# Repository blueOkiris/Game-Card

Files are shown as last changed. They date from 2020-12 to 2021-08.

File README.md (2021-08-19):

# Game Card

## Description

A business card sized portable game console utilizing buttons, multiple games, and an i2c display

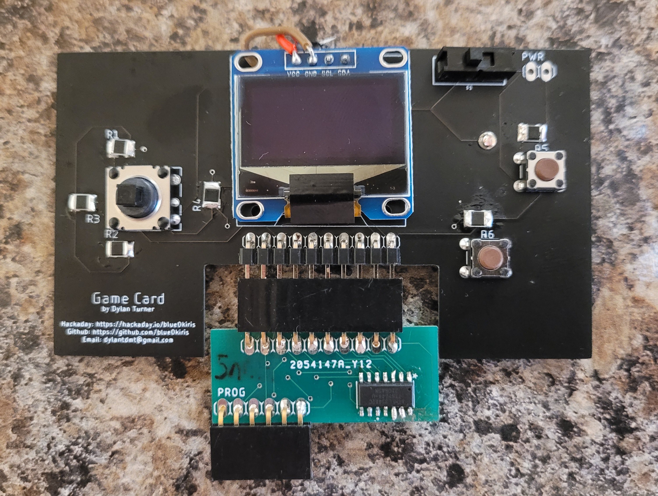
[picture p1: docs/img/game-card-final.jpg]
Game Card Final Image


[YouTube Video](https://www.youtube.com/watch?v=qE-Pg2zxOUw)

## Improving the Design (HELP!)

Right now I'm trying to redesign a new version where I can source all the electronics from manufacturers for a few reasons including:
 * Putting them up for sale
 * Decreasing cost
 * Simplifying build time

I've got everything redesigned and sourced except for the display. These little OLEDs are available everywhere except distributers it seems, and while they're like \$1-3 usually, I can't find sourcable ones for PCBs under \$10.

When the rest of the electronics costs \$4 total, it seems insane for it to be almost $15 to make.

If you can find a source I can use to build this, PLEASE let me know!

## Game List

Currently there are three games developed for the Game Card:

- Ping (1 and 2 player pong clone)
- Snek (Snake clone)
- In Progress: Tiny RPG (a very small RPG)

## More Links
 - [Info on Design](/docs/DESIGN.md)
 - [Info on Programming Cartridges](/docs/PROGRAMMING.md)
 - [Hackaday Project Page](https://hackaday.io/project/178686-game-card)

NOTE: If you're looking for the PCB designs and parts for the cartridges and cards, they're on the hackaday page

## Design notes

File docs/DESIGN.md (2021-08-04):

# Design

## Overall

The Game Card itself is nothing but a shell containing the I2C display and buttons.
Each game can then utilize the hardware how it likes and in the most efficient way possible.

The original cartridges use ATtiny84As as the brains and ROM.

Included in this repo are games designed for the system as well as header-only libraries utilizable by the various applications.

## OLED Display Connection

The OLED display is connected through the two designated I2C pins on the ATtiny84A.
These are pins 4 (SCL) and 6 (SDA) in Arduino code or 7 and 9 on the actual device.

They are also the 5th and 6th pins on the PCB port if counting from right to left.

## Button Connection

The buttons are wired in the following order:
 - Lower Button - 3rd pin from the right on PCB (first 2 are GND then VCC) which corresponds to Arduino pin 10/ATtiny pin B0
 - Higher Button - 4th pin from the right on PCB corresponding to Arduino 9/ATtiny B1
 - Up - 7th pin from the right on PCB/Arduino 8/B2
 - Down - 8th pin from the right on PCB/Arduino 7/A7
 - Left - 9th pin from the right on PCB/Arduino 5/A5
 - Right - Last pin from the right on PCB/Arduino 0/A0

Note that H and L are pulled down, but Up/Down/Left/Right are all pulled up, so they're inverted!
Just use the library though and you'll be fine :)

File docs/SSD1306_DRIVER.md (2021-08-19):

# SSD1306 Custom Driver Board

## Version 4 Need

In making Version 4 of the system, I *really* wanted to source all the parts from manufacturers so that I could order boards with the parts pre-soldered, so I could feasibly sell them.

The only sourcable I2C SSD1306 I could find was [this](https://www.newark.com/midas/mdob128064v2v-yi/oled-graphic-display-cob-128x64pixels/dp/21AH3309).

It's... okay, but at almost \$14, it outclasses all other components which total \$3.00 even.
Yeah, kinda dumb.

I looked at all the major retailers, but found no luck, despite the fact you can find them at various online stores for as low as $1.25.

Solution?
Build my own driver board. It's not as bad as it seems actually. It's pretty simple.

I'm documenting this here so I can put it in one handy place for reference. It doesn't really have to do with code itself though.

## I2C Selection

These boards can communicate in a variety of ways, including Parallel, SPI, and IIC.
I've always used I2C for these throughout the project, and I want full compatibility with the current codebase (though I think I may be able to do parallel, so that is unfortunate, but it's too late).

Anyway, that selection has to be done in hardware by tying various pins together on the ribbon cable.

The datasheet is pretty helpful in this regard.

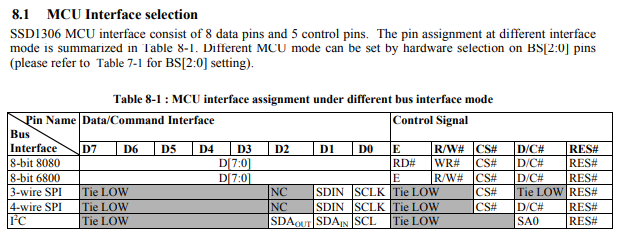
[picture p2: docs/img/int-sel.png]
int-sel


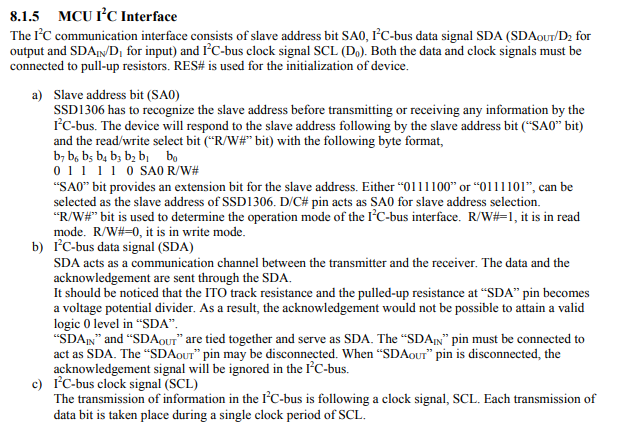
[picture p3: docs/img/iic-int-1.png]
iic-int-1


Things to note:
* Looking at the current driver board and code, I know that the SA0 bit is tied to ground as the I2C address is 0x3C.
* The R/W\# pin is obviously tied to ground because we want to write to it
* SDA\_in and SDA\_out are tied to together for one SDA
* D7:3 are tied to GND while D2:1 are tied to SDA.
* E and CS# are both low
* Reset is high bc we don't want it to reset.

## Driver Circuit

Adafruit provides a driver circuit that I think I can use as a reference for my own design:

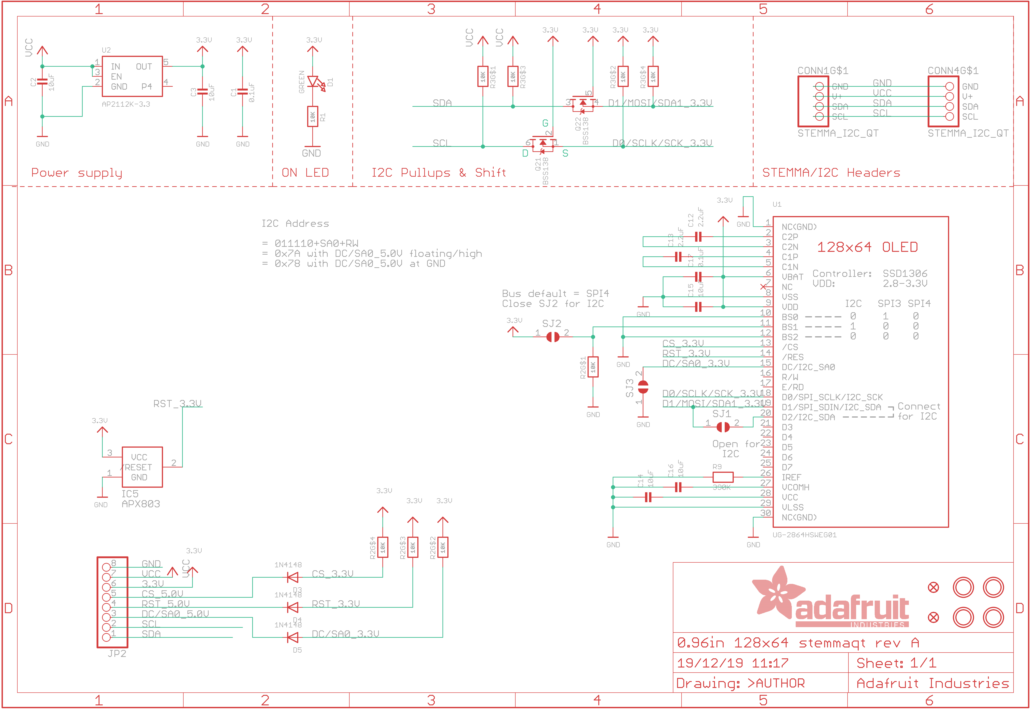
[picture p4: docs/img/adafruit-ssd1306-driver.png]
adafruit i2c display circuit


It's... okay.
I found a simpler one though:

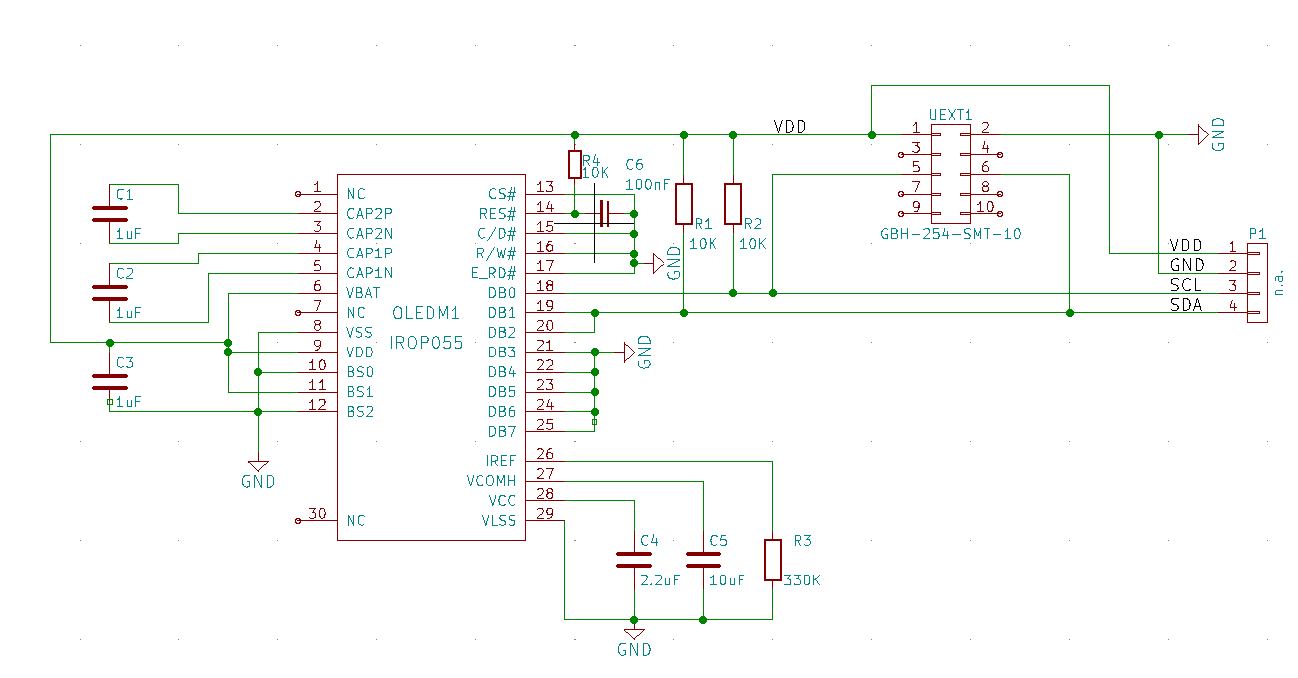
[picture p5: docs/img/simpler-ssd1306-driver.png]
simpler i2c ssd1306


But I'm not certain it's actually setting everything up correctly.

Got it from [here](https://www.olimex.com/Products/Modules/LCD/MOD-OLED-128x64/open-source-hardware)

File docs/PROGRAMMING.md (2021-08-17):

# Programming a Cartridge

## Info

This assumes you are using the standard ATtiny84 cartridges.

This is how to set up your dev environment to be able to get these programs to those game cartridges.

## Install build tool

First, install `make`.

If you're on windows, install MinGW from [here](http://sourceforge.net/projects/mingw-w64/files/Toolchains%20targetting%20Win32/Personal%20Builds/mingw-builds/installer/mingw-w64-install.exe/download)

That will give you access to the command `mingw32-make` which is an equivalent to `make` on Linux.

Linux users, simply use your package manager to install make. On Ubuntu/Debian, the package is within "build-essential."

After that, go to the official arduino page and install the Arduino IDE.

NOTE: If you're on Linux, you also need to change lines 6 and 7 of arduino-cli.yaml to use / instead of \\!

## Setup UNO

Open up the Arduino IDE and find the example "ArduinoISP" program in the Arduino IDE, select the UNO from the menu (noting the PORT for later), and program the UNO with the Arduino ISP program.

Once you've configured your UNO as a programmer, you won't need to open the IDE again.

## Connect Board

Once you have make, and your UNO is set up, you'll need to connect the cartridge to an Arduino UNO.

From Right to left on Programming port the connections are 5V, GND, 12, 11, 13, and 10

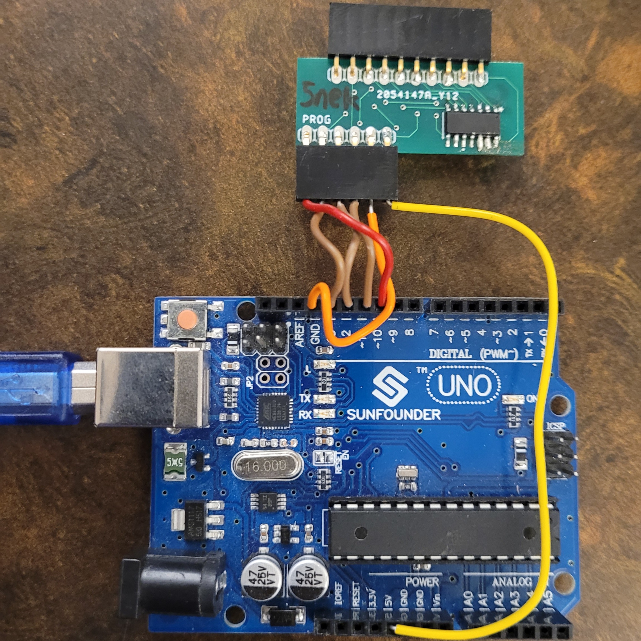
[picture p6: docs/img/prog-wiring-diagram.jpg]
prog-wiring-diagram


## Burn-Bootloader

With everything set up, first burn the bootloader:
 - Linux: `make burn-bootloader PORT=#####`
 - Windows: `mingw32-make burn-bootloader PORT=#####`

Replace the pound signs after `PORT=` with the UNO's port from earlier.

## Program Game

Then program the game!

 - Linux: `make PORT=##### GAME=#####`
 - Windows: `mingw32-make PORT=##### GAME=#####`

Once again, replace the pound signs after `PORT=` with the UNO's port from earlier, but also replace the pound signs after `GAME=` with the name of the game you'd like to program be that Snek, Ping, or otherwise.

And you're done!

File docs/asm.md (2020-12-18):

# Assembly Programming Guide

## Description

Here I describe how to program for the Game Card in Game Card Assembly using the Game Card Assembler (gca).

See [example.gca](./example.gca) for an example of gca code

## Instructions

__Memory Control__

There are several commands for manipulating memory.

Some can set tile mem, background mem, and sprite mem, but those are the most complicated. I'll start first with registers and move from there.

The first instruction we'll look at is `mov`

`mov` takes a register indicated by "reg" followed by an index, a comma, and a value which is either an integer value, a hex value, or another register.

This command takes whatever datum follows the column and stores it in the register.

Examples:
- `mov reg0, 1237`
- `mov reg1, reg0`
- `mov reg2, 0xF78`

Adding onto that are arithmetic commands which store the value of the first register plussed or minused or whatever with the value back into the first register.

So `add reg1, reg2` is like `reg1 += reg2` or `reg1 = reg1 + reg2`

So you have `add` for `+`, `sub` for `-`, `mul` for `*`, `div` for `/`, `ls` for left shift, `rs` for right shift.

Now these can also apply to parts of sprite memory, specifically a sprites x and y position:
- `mov sprx, 0, 10`
- `add spry, reg1, 0x57`

Note:
 - There are *3* comma separated values. The first is sprx or spry, the second is which sprite you want to change, and the third is the new value as per the register versions
 - sprx and spry cannot be in the value part of the command

Even more specialized are the sprite's tile index, `spri`, a background location's tile index, `bgi`, an entire sprite, `spr`, and tiles, `tile`

__Graphical Setting__

<u>Sprites:</u>
Set an entire sprite by providing index, x, y, and then tile:

`spr <sprite index>, <x position>, <y position>, <tile index>`
All of these can be registers or discrete numbers (including hex)

Example:
`spr 0, 5, 5, 1` sets sprite 0 to be at position (5, 5) with image #1

<u>Backgrounds:</u>
`bgi` Works similarly, but with less values, just index and tile:
`bgi <bg index>, <tile index>`

Example:
`bgi reg0, 0x0F`

<u> Tiles: </u>
`tile` takes an index followed by 8 bytes representing columns

Example:
`tile 1, 0xFF, 0x81, 0x81, 0x81, 0x81, 0x81, 0x81, 0xFF` sets the tile at index 1 to be a box

__Labels and Jumps__

The other part of the assembly language is control flow

You can set named points in a program to jump to either unconditionally or with condition.

A name plus ':' makes a label - `label_name_HERE69:`
You can then jump to it with `jmp label_nameHERE69`

These jumps can be based on conditions:
 - `je` - Jump if equal
 - `jne` - Jump if not equal
 - `jl` - Jump if less than
 - `jg` - Jump if greater than
 - `jle` - Jump if less than or equal
 - `jge` - Jump if greater than or equal

The way you set those conditions is with `cmp` (compare)

`cmp` takes two registers and compares them, setting an internal register which can be used in conditional jumps

Example:
```
label_for_loop:
    cmp reg0, reg1
    jg label_if_reg0_is_greater_than
    mov reg0, reg1
    add reg0, 1
    jmp label_for_loop
label_if_reg0_is_greater_than:
```

This code will compare reg0 to reg1, and if reg0 is NOT greater than reg1, it will set reg0 to reg1 + 1 then jump back to compare again.

If reg0 WAS greater than reg1, or the second time through where it MUST be reg0, then it will jump out of the loop to `label_if_reg0_is_greater_than`

__Comments__

Comments are anything following a ';' until a new line

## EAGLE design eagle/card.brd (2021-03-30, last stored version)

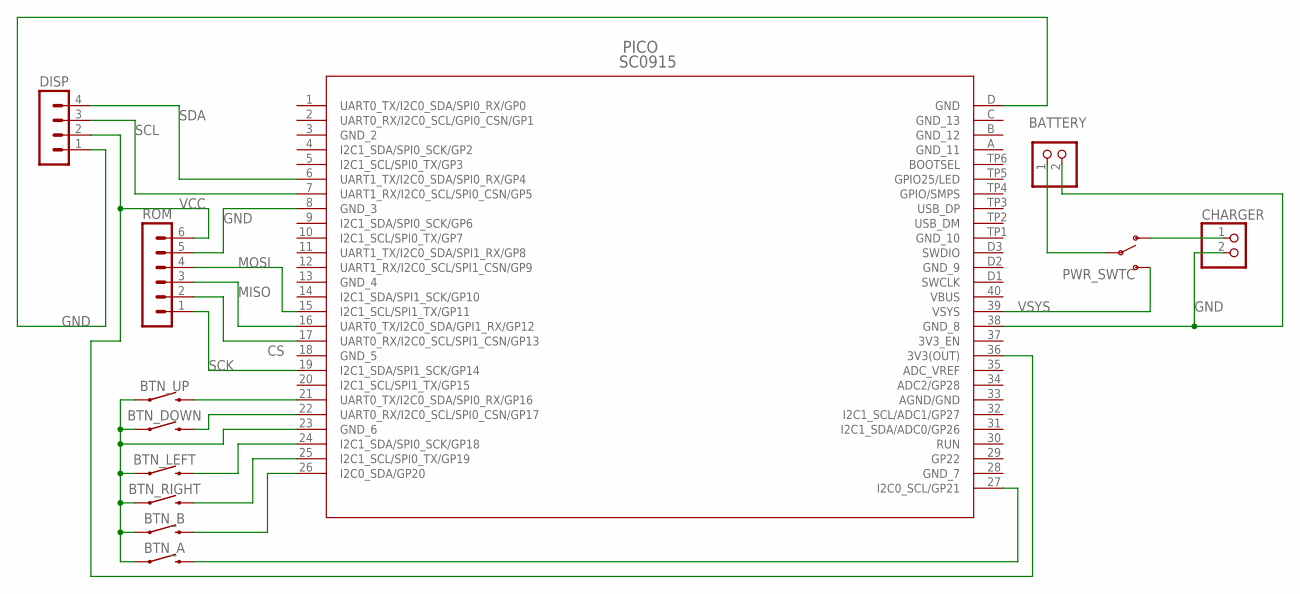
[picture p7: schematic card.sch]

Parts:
BATTERY: PINHD-1X2; 1X02
BTN_A: MOMENTARY-SWITCH-SPST-PTH-6.0MM; TACTILE_SWITCH_PTH_6.0MM
BTN_B: MOMENTARY-SWITCH-SPST-PTH-6.0MM; TACTILE_SWITCH_PTH_6.0MM
BTN_DOWN: MOMENTARY-SWITCH-SPST-PTH-6.0MM; TACTILE_SWITCH_PTH_6.0MM
BTN_LEFT: MOMENTARY-SWITCH-SPST-PTH-6.0MM; TACTILE_SWITCH_PTH_6.0MM
BTN_RIGHT: MOMENTARY-SWITCH-SPST-PTH-6.0MM; TACTILE_SWITCH_PTH_6.0MM
BTN_UP: MOMENTARY-SWITCH-SPST-PTH-6.0MM; TACTILE_SWITCH_PTH_6.0MM
CHARGER: PINHD-1X2; 1X02
DISP: MA04-1
PICO: SC0915; SC0915_RPI
PWR_SWTC: SWITCH-SPDT-PTH-11.6X4.0MM; SWITCH_SPDT_PTH_11.6X4.0MM
ROM: MA06-1

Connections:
3V3_EN: PICO.37 (3V3_EN)
ADC_VREF: PICO.35 (ADC_VREF)
CS: PICO.17 (UART0_RX/I2C0_SCL/SPI1_CSN/GP13), ROM.2
GND: BATTERY.2, BTN_A.1, BTN_B.1, BTN_DOWN.1, BTN_LEFT.1, BTN_RIGHT.1, BTN_UP.1, CHARGER.2, DISP.1, PICO.8 (GND_3), PICO.23 (GND_6), PICO.38 (GND_8), PICO.D (GND), ROM.5
MISO: PICO.16 (UART0_TX/I2C0_SDA/GPI1_RX/GP12), ROM.3
MOSI: PICO.15 (I2C1_SCL/SPI1_TX/GP11), ROM.4
unnamed: BTN_UP.3 (2), PICO.21 (UART0_TX/I2C0_SDA/SPI0_RX/GP16)
unnamed: BTN_DOWN.3 (2), PICO.22 (UART0_RX/I2C0_SCL/SPI0_CSN/GP17)
unnamed: BTN_LEFT.3 (2), PICO.24 (I2C1_SDA/SPI0_SCK/GP18)
unnamed: BTN_RIGHT.3 (2), PICO.25 (I2C1_SCL/SPI0_TX/GP19)
unnamed: BTN_B.3 (2), PICO.26 (I2C0_SDA/GP20)
unnamed: BTN_A.3 (2), PICO.27 (I2C0_SCL/GP21)
unnamed: BATTERY.1, PWR_SWTC.2
unnamed: CHARGER.1, PWR_SWTC.1 (O)
SCK: PICO.19 (I2C1_SDA/SPI1_SCK/GP14), ROM.1
SCL: DISP.3, PICO.7 (UART1_RX/I2C0_SCL/SPI0_CSN/GP5)
SDA: DISP.4, PICO.6 (UART1_TX/I2C0_SDA/SPI0_RX/GP4)
VBUS: PICO.40 (VBUS)
VCC: DISP.2, PICO.36 (3V3(OUT)), ROM.6
VSYS: PICO.39 (VSYS), PWR_SWTC.3 (S)

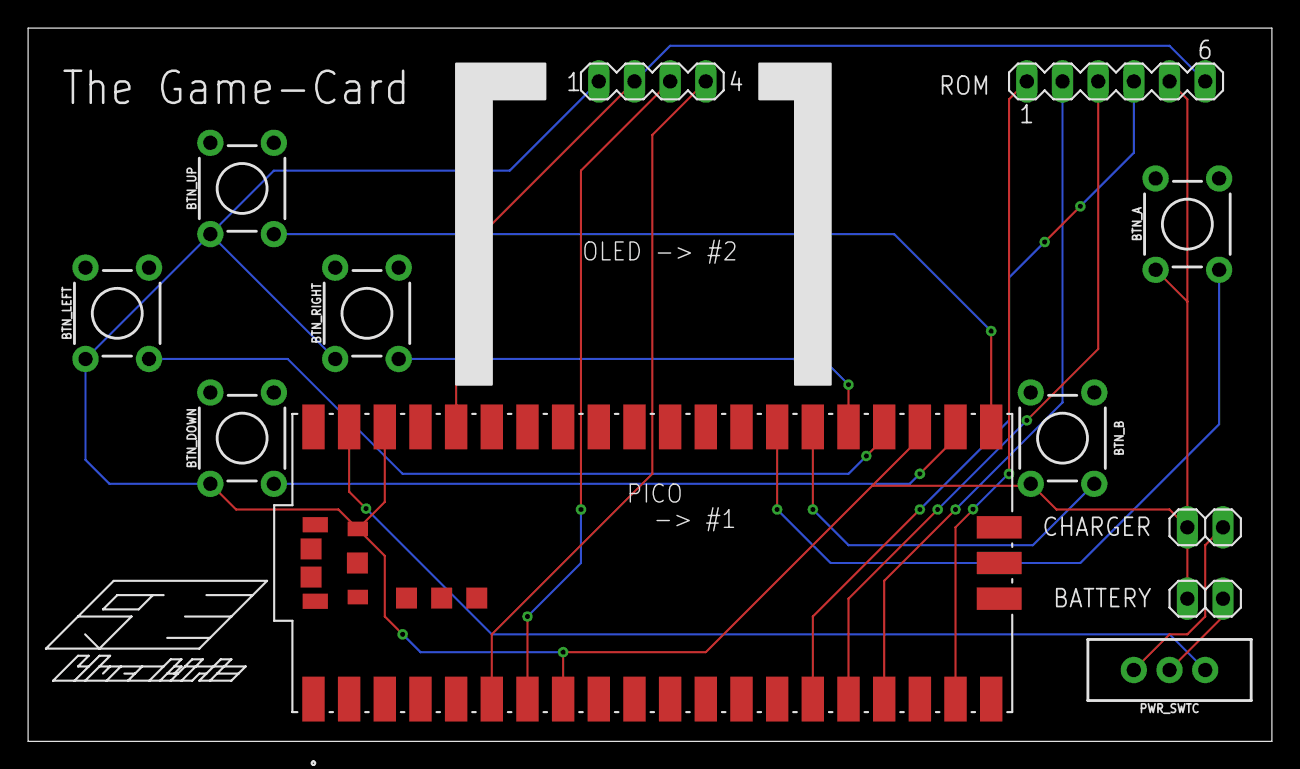
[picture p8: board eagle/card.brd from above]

Board: 2 copper layers, 88.6 x 50.8 mm, 12 parts (0 on the bottom side), 17 nets.

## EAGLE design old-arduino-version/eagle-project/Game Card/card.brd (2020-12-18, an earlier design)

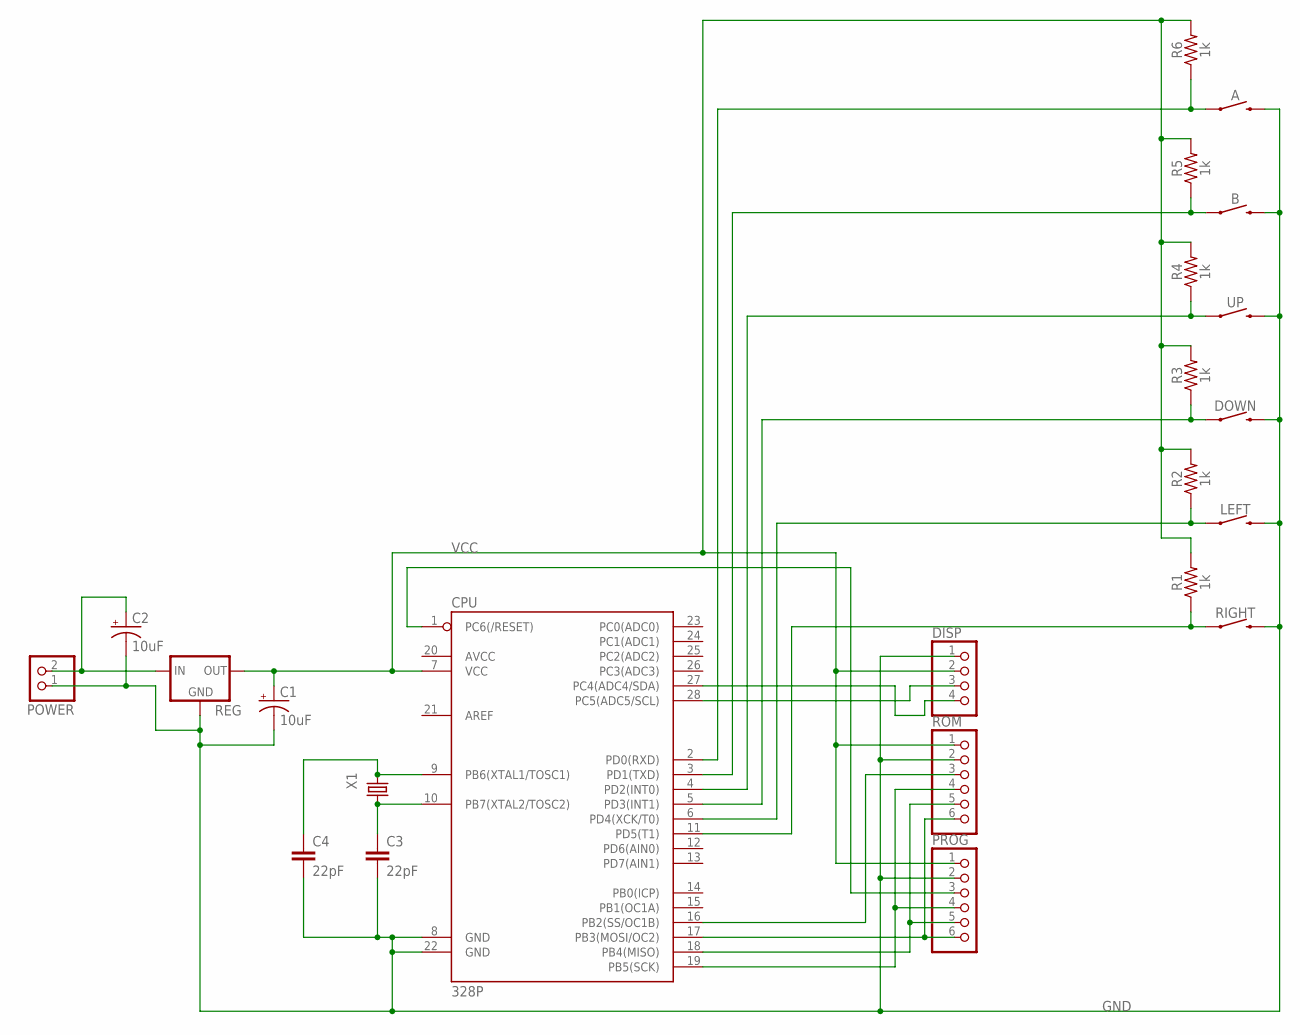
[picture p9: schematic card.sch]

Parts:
A: MOMENTARY-SWITCH-SPST-PTH-6.0MM; TACTILE_SWITCH_PTH_6.0MM
B: MOMENTARY-SWITCH-SPST-PTH-6.0MM; TACTILE_SWITCH_PTH_6.0MM
C1, C2: 10uF; CPOL-RADIAL-2.5MM-5MM
C3, C4: 22pF; CAP-PTH-2.54
CPU: 328P; DIP28
DISP: PINHD-1X4; 1X04
DOWN: MOMENTARY-SWITCH-SPST-PTH-6.0MM; TACTILE_SWITCH_PTH_6.0MM
LEFT: MOMENTARY-SWITCH-SPST-PTH-6.0MM; TACTILE_SWITCH_PTH_6.0MM
POWER: PINHD-1X2; 1X02
PROG: PINHD-1X6; 1X06
R1, R2, R3, R4, R5, R6: 1k; AXIAL-0.3
REG: R-78E5.0-1.0; DC-DC_CONVERTER_78XX
RIGHT: MOMENTARY-SWITCH-SPST-PTH-6.0MM; TACTILE_SWITCH_PTH_6.0MM
ROM: PINHD-1X6; 1X06
UP: MOMENTARY-SWITCH-SPST-PTH-6.0MM; TACTILE_SWITCH_PTH_6.0MM
X1: CRYSTALS-NOGND-HC49; HC49

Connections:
GND: A.3 (2), B.3 (2), C1.2 (-), C2.2 (-), C3.2, C4.2, CPU.8 (GND), CPU.22 (GND), DISP.1, DOWN.3 (2), LEFT.3 (2), POWER.1, PROG.2, REG.GND, RIGHT.3 (2), ROM.2, UP.3 (2)
unnamed: CPU.17 (PB3(MOSI/OC2)), PROG.6, ROM.6
unnamed: CPU.18 (PB4(MISO)), PROG.5, ROM.5
unnamed: CPU.19 (PB5(SCK)), PROG.4, ROM.4
unnamed: CPU.1 (PC6(/RESET)), PROG.3
unnamed: A.1, CPU.2 (PD0(RXD)), R6.P$1 (1)
unnamed: C2.1 (+), POWER.2, REG.VIN (IN)
unnamed: CPU.16 (PB2(SS/OC1B)), ROM.3
unnamed: CPU.28 (PC5(ADC5/SCL)), DISP.3
unnamed: CPU.27 (PC4(ADC4/SDA)), DISP.4
unnamed: C4.1, CPU.9 (PB6(XTAL1/TOSC1)), X1.2
unnamed: B.1, CPU.3 (PD1(TXD)), R5.P$1 (1)
unnamed: CPU.4 (PD2(INT0)), R4.P$1 (1), UP.1
unnamed: CPU.5 (PD3(INT1)), DOWN.1, R3.P$1 (1)
unnamed: CPU.6 (PD4(XCK/T0)), LEFT.1, R2.P$1 (1)
unnamed: CPU.11 (PD5(T1)), R1.P$1 (1), RIGHT.1
unnamed: C3.1, CPU.10 (PB7(XTAL2/TOSC2)), X1.1
VCC: C1.1 (+), CPU.7 (VCC), DISP.2, PROG.1, R1.P$2 (2), R2.P$2 (2), R3.P$2 (2), R4.P$2 (2), R5.P$2 (2), R6.P$2 (2), REG.VOUT (OUT), ROM.1

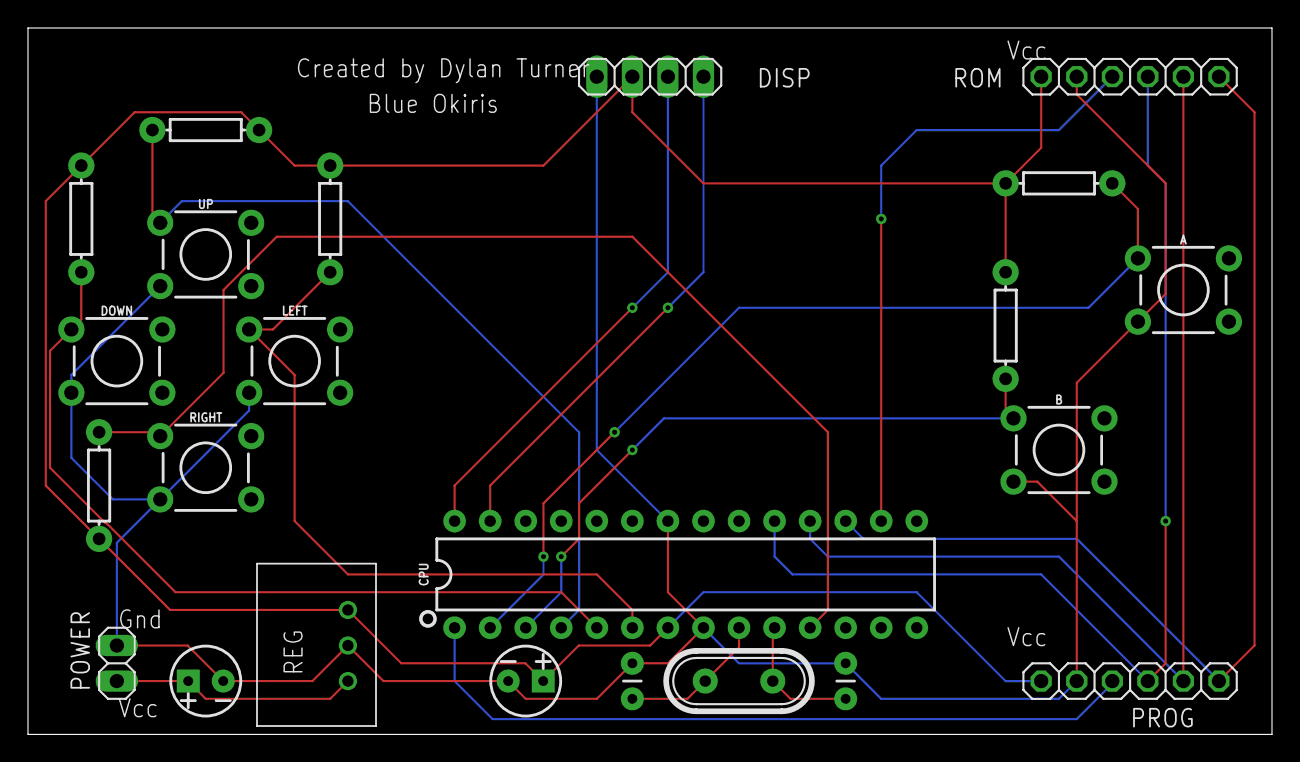
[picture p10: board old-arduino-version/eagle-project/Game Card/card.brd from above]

Board: 2 copper layers, 88.9 x 50.5 mm, 23 parts (0 on the bottom side), 18 nets.

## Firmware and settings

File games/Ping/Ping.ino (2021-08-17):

/*
 * Author: Dylan Turner
 * Description: A pong clone for 1 and 2 players
 */

#include <GameCardDisplay.hpp>
#include <GameCardControls.hpp>
#include "State.hpp"
#include "Sprites.hpp"

const gamecard::Ssd1306 g_disp;
const gamecard::ButtonController g_cont;
GameState g_state;

void setup(void) {
    g_disp.init();
    g_cont.init();
}

void loop(void) {
    switch(g_state.curr) {
        case GameState::StateName::Menu:
            g_state.reset();
            g_disp.fill(true);
            
            drawMenu();

            // Wait for player count
            while(!g_state.twoPlayer) {
                if(g_cont.isInputPressed(gamecard::Input::High)) {
                    break;
                } else if(g_cont.isInputPressed(gamecard::Input::Low)) {
                    g_state.twoPlayer = true;
                }
            }

            // Continue
            randomSeed(millis());
            g_state.curr = GameState::StateName::Game;
            resetPostScore();
            break;

        case GameState::StateName::Game:
            drawScore();
            
            drawPaddles();
            movePaddles();

            clearBall();
            moveBallAndScore();
            drawBall();

            /*
             * Switching to TinyWireM
             * didn't just save memory
             * it drastically improved draw speeds
             * so we have to delay now
             * (This is a good thing)
             */
            delay(5);
            break;

        case GameState::StateName::End:
            g_disp.fill(true);
            drawWinner();
            while(!g_cont.isInputPressed(gamecard::Input::High));
            delay(1);
            while(g_cont.isInputPressed(gamecard::Input::High));
            g_state.curr = GameState::StateName::Menu;
            break;
    }
}

bool updateMoveDirection(
        bool *pressedRef, float *heightRef, gamecard::Input inp,
        uint8_t drawX, bool isUp) {
    if(!(*pressedRef) && g_cont.isInputPressed(inp)
            && ((isUp && *heightRef > 0) || (!isUp && *heightRef < 7))) {
        g_disp.putTile(g_backSprs[0], drawX, *heightRef);

        *pressedRef = true;
        (*heightRef) += isUp ? -1 : 1;
    } else if(!g_cont.isInputPressed(inp)) {
        *pressedRef = false;
    }
}

void movePaddles() {
    // Player 1 Control
    updateMoveDirection(
        &g_state.justPressed[0], &g_state.playerHeight[0],
        gamecard::Input::Up, 0, true
    );
    updateMoveDirection(
        &g_state.justPressed[1], &g_state.playerHeight[0],
        gamecard::Input::Down, 0, false
    );

    // Player 2 Control
    if(g_state.twoPlayer) { // Manual
        updateMoveDirection(
            &g_state.justPressed[2], &g_state.playerHeight[1],
            gamecard::Input::High, 15, true
        );
        updateMoveDirection(
            &g_state.justPressed[3], &g_state.playerHeight[1],
            gamecard::Input::Low, 15, false
        );
    } else { // AI
        if(!g_state.aiPlayerDown && g_state.playerHeight[1] < 0.5) {
            g_state.playerHeight[1] += 0.1;
            g_state.aiPlayerDown = true;
        } else if(g_state.aiPlayerDown && g_state.playerHeight[1] > 6.5) {
            g_state.playerHeight[1] -= 0.1;
            g_state.aiPlayerDown = false;
        } else {
            g_state.playerHeight[1] += g_state.aiPlayerDown ? 0.4 : -0.4;
        }
        if(g_state.lastAiTile
                != static_cast<uint8_t>(g_state.playerHeight[1])) {
            g_disp.putTile(g_backSprs[0], 15, g_state.lastAiTile);
            g_state.lastAiTile = static_cast<uint8_t>(g_state.playerHeight[1]);
        }
    }
}

void drawPaddles(void) {
    g_disp.putTile(
        g_paddleSpr, 0, static_cast<uint8_t>(g_state.playerHeight[0])
    );
    g_disp.putTile(
        g_paddleSpr, 15, static_cast<uint8_t>(g_state.playerHeight[1])
    );
}

void drawWinner(void) {
    uint8_t sprite[8];
    const int wnrRow = 3, wnrCol = 4;
    const uint8_t wnrMsg[8] = {
        FONT_P, g_state.p1Wins ? FONT_1 : FONT_2, FONT_SPACE, FONT_SPACE,
        FONT_W, FONT_I, FONT_N, FONT_S
    };
    for(int i = 0; i < 8; i++) {
        g_disp.putTile(g_fontSprs[wnrMsg[i]], wnrCol + i, wnrRow);
    }
}

void drawScore(void) {
    g_disp.putTile(g_fontSprs[FONT_0 + g_state.playerScore[0]], 2, 1);
    g_disp.putTile(g_fontSprs[FONT_0 + g_state.playerScore[1]], 13, 1);
}

void clearBall(void) {
    g_disp.putOffsetTile(
        static_cast<uint8_t>(g_state.ballPos[0]),
        static_cast<uint8_t>(g_state.ballPos[1]),
        g_backSprs[0], g_backSprs
    );
}

void moveBallAndScore(void) {
    g_state.ballPos[0] += g_state.ballVel[0];
    g_state.ballPos[1] += g_state.ballVel[1];
    
    if(g_state.ballPos[0] < 8
            && g_state.ballPos[1]
                < static_cast<uint8_t>(g_state.playerHeight[0]) * 8 + 8
            && g_state.ballPos[1] + 8
                > static_cast<uint8_t>(g_state.playerHeight[0]) * 8) {
        g_state.ballVel[0] = g_state.baseBallSpeed
            + (random(0, g_state.maxBallExtra * 10) / 10.0f);
        g_state.ballPos[0] = 9;
    } else if(g_state.ballPos[0] > 111
            && g_state.ballPos[1]
                < static_cast<uint8_t>(g_state.playerHeight[1]) * 8 + 8
            && g_state.ballPos[1] + 8
                > static_cast<uint8_t>(g_state.playerHeight[1]) * 8) {
        g_state.ballVel[0] = -g_state.baseBallSpeed
            + (random(0, g_state.maxBallExtra * 10) / 10.0f);
        g_state.ballPos[0] = 110;
    } else if(g_state.ballPos[0] < 1) {
        g_state.playerScore[1]++;
        
        if(g_state.playerScore[1] > 7) {
            g_state.p1Wins = false;
            g_disp.fill(true);
            g_state.curr = GameState::StateName::End;
        } else {        
            resetPostScore();
        }
    }  else if(g_state.ballPos[0] > 119) {
        g_state.playerScore[0]++;
        
        if(g_state.playerScore[0] > 7) {
            g_state.p1Wins = true;
            g_disp.fill(true);
            g_state.curr = GameState::StateName::End;
        } else {
            resetPostScore();
        }
    } else if(g_state.ballPos[1] > 55) {
        g_state.ballVel[1] = -g_state.baseBallSpeed
            + (random(0, g_state.maxBallExtra * 10) / 10.0f);
        g_state.ballPos[1] = 54;
    } else if(g_state.ballPos[1] < 1) {
        g_state.ballVel[1] = g_state.baseBallSpeed
            + (random(0, g_state.maxBallExtra * 10) / 10.0f);
        g_state.ballPos[1] = 2;
    }
}

void resetPostScore(void) {
    // Reset positions
    g_state.playerHeight[0] = 3;
    g_state.playerHeight[1] = 3;
    g_state.ballPos[0] = SSD_SCREEN_WIDTH / 2 - 4;
    g_state.ballPos[1] = SSD_SCREEN_HEIGHT / 2 - 4;
    g_state.ballVel[0] =
        (g_state.baseBallSpeed
            + (random(0, g_state.maxBallExtra * 10) / 10.0f))
        * (random(0, 2) ? -1 : 1);
    g_state.ballVel[1] =
        (g_state.baseBallSpeed
            + (random(0, g_state.maxBallExtra * 10) / 10.0f))
        * (random(0, 2) ? -1 : 1);
    
    // Redraw everything
    g_disp.fill(true);
    drawScore();
    drawBall();
    delay(1000);
}

void drawBall(void) {
    g_disp.putOffsetTile(
        static_cast<uint8_t>(g_state.ballPos[0]),
        static_cast<uint8_t>(g_state.ballPos[1]),
        g_ballSpr, g_backSprs
    );
}

void drawMenu(void) {
    // Print title
    const int titleRow = 1, titleCol = 6;
    const uint8_t title[4] = {
        FONT_P, FONT_I, FONT_N, FONT_G
    };
    for(int i = 0; i < 4; i++) {
        g_disp.putTile(g_fontSprs[title[i]], titleCol + i, titleRow);
    }

    // Draw the 1 player option: 1P-H
    const int p1OpRow = 5, p1OpCol = 2;
    const uint8_t p1Op[4] = {
        FONT_1, FONT_P, FONT_DASH, FONT_H
    };
    for(int i = 0; i < 4; i++) {
        g_disp.putTile(g_fontSprs[p1Op[i]], p1OpCol + i, p1OpRow);
    }
    
    // Draw the 2 player option: 2P-L
    const int p2OpRow = 5, p2OpCol = 10;
    const uint8_t p2Op[4] = {
        FONT_2, FONT_P, FONT_DASH, FONT_L
    };
    for(int i = 0; i < 4; i++) {
        g_disp.putTile(g_fontSprs[p2Op[i]], p2OpCol + i, p2OpRow);
    }
}

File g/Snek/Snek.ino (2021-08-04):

/*
 * Author: Dylan Turner
 * Description: Snake clone. Game ends after getting all foods (128)
 */

#include <GameCardDisplay.hpp>
#include <GameCardControls.hpp>
#include "State.hpp"
#include "Sprites.hpp"

const gamecard::Ssd1306 g_disp;
const gamecard::ButtonController g_cont;
GameState g_state;

void setup(void) {
    g_disp.init();
    g_cont.init();
}

void loop(void) {
    switch(g_state.curr) {
        case GameState::StateName::Menu: {
            const uint8_t titleMsg[4] = {
                FONT_S, FONT_N, FONT_E, FONT_K
            };
            print(titleMsg, 4, 6, 3);

            while(!g_cont.isInputPressed(gamecard::Input::High));
            randomSeed(millis());
            g_state.reset();
            g_state.curr = GameState::StateName::Game;
            g_disp.fill(true);
            drawWalls();
            drawSnake();
            drawFood();
            delay(1000);
        } break;

        case GameState::StateName::Game:
            moveSnake();
            updateSpriteIfMovedTile();
            changeDir();

            score();
            
            if(dead()) {
                delay(1000);
                g_disp.fill(true);
                g_state.curr = GameState::StateName::Dead;
            }
            if(g_state.score == 83) {
                g_state.curr = GameState::StateName::Win;
            }
            break;
        
        case GameState::StateName::Dead: {
            const uint8_t deathMsg[4] = {
                FONT_D, FONT_E, FONT_A, FONT_D
            };
            print(deathMsg, 4, 6, 2);

            const uint8_t score[2] = {
                (g_state.score / 10) % 10,
                g_state.score % 10
            };
            printNums(score, 2, 7, 4);
            
            while(!g_cont.isInputPressed(gamecard::Input::High));
            delay(1);
            while(g_cont.isInputPressed(gamecard::Input::High));
            g_state.curr = GameState::StateName::Menu;
            g_disp.fill(true);
        } break;
            
        case GameState::StateName::Win: {
            const uint8_t winMsg[3] = {
                FONT_W, FONT_I, FONT_N
            };
            print(winMsg, 3, 6, 3);
            
            while(!g_cont.isInputPressed(gamecard::Input::High));
            delay(1);
            while(g_cont.isInputPressed(gamecard::Input::High));
            g_state.curr = GameState::StateName::Menu;
            g_disp.fill(true);
        } break;
    }
}

void score(void) {
    if(g_state.tile == g_state.foodPos) {
        g_state.score++;
        g_state.plyrSpd += g_state.acc;
        
        do {
            g_state.foodPos = (random(1, 15) << 4) + random(1, 7);
        } while(g_state.foodInSnake());
        drawFood();
    }
}

void changeDir(void) {
    if(g_cont.isInputPressed(gamecard::Input::Up)) {
        g_state.plyrDir = GameState::Dir::Up;
    } else if(g_cont.isInputPressed(gamecard::Input::Down)) {
        g_state.plyrDir = GameState::Dir::Down;
    } else if(g_cont.isInputPressed(gamecard::Input::Left)) {
        g_state.plyrDir = GameState::Dir::Left;
    } else if(g_cont.isInputPressed(gamecard::Input::Right)) {
        g_state.plyrDir = GameState::Dir::Right;
    }
}

void drawWalls(void) {
    for(int i = 1; i < 15; i++) {
        g_disp.putTile(g_wallSprs[0], i, 0);
        g_disp.putTile(g_wallSprs[1], i, 7);
    }
    for(int i = 1; i < 7; i++) {
        g_disp.putTile(g_wallSprs[2], 0, i);
        g_disp.putTile(g_wallSprs[3], 15, i);
    }
}

bool dead(void) {
    if((g_state.tile >> 4) == 15 || (g_state.tile >> 4) == 0
            || (g_state.tile & 0x0F) == 7 || (g_state.tile & 0x0F) == 0) {
        return true;
    }

    for(int i = 1; i < g_state.score; i++) {
        if(g_state.tile == g_state.plyrBodyPos[i - 1]) {
            return true;
        }
    }

    return false;
}

void updateSpriteIfMovedTile(void) {
    uint8_t newTile =
        ((static_cast<uint8_t>(g_state.plyrHeadPos[0]) / 8) << 4)
        + static_cast<uint8_t>(g_state.plyrHeadPos[1]) / 8;
    if(newTile != g_state.tile) {
        // Clear the furthest body part (not head bc head will be replaced)
        g_disp.putTile(
            g_blankSpr,
            g_state.plyrBodyPos[g_state.score - 2] >> 4,
            g_state.plyrBodyPos[g_state.score - 2] & 0x0F
        );
        
        // Set body parts to follow their parent
        for(int i = g_state.score - 2; i >= 1; i--) {
            g_state.plyrBodyPos[i] = g_state.plyrBodyPos[i - 1];
        }

        // Set the first body part to follow the old head
        g_state.plyrBodyPos[0] = g_state.tile;

        // Update head
        g_disp.putTile(
            g_blankSpr, g_state.tile >> 4, g_state.tile & 0x0F
        );
        g_state.tile = newTile;

        // Draw the head and last part
        g_disp.putTile(g_snekHead, g_state.tile>> 4, g_state.tile & 0x0F);
        g_disp.putTile(
            g_snekSpr,
            g_state.plyrBodyPos[0] >> 4, g_state.plyrBodyPos[0] & 0x0F
        );
        g_disp.putTile(
            g_snekSpr,
            g_state.plyrBodyPos[g_state.score - 2] >> 4,
            g_state.plyrBodyPos[g_state.score - 2] & 0x0F
        );
    }
}

void moveSnake(void) {
    switch(g_state.plyrDir) {
        case GameState::Dir::Up:
            g_state.plyrHeadPos[1] -= g_state.plyrSpd;
            break;
        
        case GameState::Dir::Down:
            g_state.plyrHeadPos[1] += g_state.plyrSpd;
            break;
        
        case GameState::Dir::Left:
            g_state.plyrHeadPos[0] -= g_state.plyrSpd;
            break;
        
        case GameState::Dir::Right:
            g_state.plyrHeadPos[0] += g_state.plyrSpd;
            break;
    }
}

void drawSnake(void) {
    g_disp.putTile(
        g_snekHead, g_state.tile >> 4, g_state.tile & 0x0F
    );
    for(int i = 1; i < g_state.score; i++) {
        g_disp.putTile(
            g_snekSpr,
            g_state.plyrBodyPos[i - 1] >> 4,
            g_state.plyrBodyPos[i - 1] & 0x0F
        );
    }
}

void drawFood(void) {
    g_disp.putTile(g_foodSpr, g_state.foodPos >> 4, g_state.foodPos & 0x0F);
}

void printNums(
        uint8_t *nums, const int len,
        const uint8_t startCol, const uint8_t startRow) {
    char spr[8];
    for(int i = 0; i < len; i++) {
        for(int j = 0; j < 8; j++) {
            spr[j] = pgm_read_byte(g_numSprs + nums[i] * 8 + j);
        }
        g_disp.putTile(spr, startCol + i, startRow);
    }
}

void print(
        uint8_t *letters, const int len,
        const uint8_t startCol, const uint8_t startRow) {
    char spr[8];
    for(int i = 0; i < len; i++) {
        for(int j = 0; j < 8; j++) {
            spr[j] = pgm_read_byte(g_letters + letters[i] * 8 + j);
        }
        g_disp.putTile(spr, startCol + i, startRow);
    }
}

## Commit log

2020-12-16 Fixed display driver code
    [GameCard.ino, Oled.cpp]
2020-12-16 Integrated SSD1306 driver into OLED wrapper
2020-12-16 Fixed sprite and tile based graphics
    [GameCard.ino, Oled.cpp, Oled.hpp]
2020-12-17 Added registers and control flow instructions
2020-12-17 Bug fixes and working loops in demo
    [Device.cpp, GameCard.ino]
2020-12-17 Achieved communication with Arduino over serial in c#
2020-12-17 Added C# project for writing assembler
2020-12-17 Added ebnf for assembler
2020-12-17 Added files intended for use in assembler application
2020-12-17 Finished parser for assembler
2020-12-18 Implemented mov, add, sub, etc instructions to assembly language
2020-12-18 Implemented spr instruction in assembler
2020-12-18 Implemented spri instruction in assembler
2020-12-18 Implemented upd instruction in assembler
2020-12-18 Implemented jump command in assembly
2020-12-18 Had to switch to 25LC512 instead of 1024 which means a 16-bit address instead of a 24-bit address, so I've adjusted code to work with that
2020-12-18 Added assembly guide
2020-12-18 Added board files to project
    [card.brd, card.sch, cartridge.brd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]
2020-12-20 Implemented buttons. Buttons are read from PORTD and placed in register 0. This can of course be changed, but that's how the PCB is set up
2020-12-21 Modified example program to use buttons
2020-12-21 Updated testApp code (and fixed bug problem)
    [GameCard.ino]
2021-03-24 Shifted towards development for the pico
    [card.brd, card.sch, cartridge.brd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]
2021-03-24 Made the old arduino code into a zip instead of folder
    [card.brd, card.sch, cartridge.brd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]
2021-03-25 Created interfaces for the hardware so that VirtualMachine will be able to have different implementations. For instance instead of Oled, Buttons, and 23A1024, somebody could use an LCD, an analog sti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
2021-03-25 Implemented display control on second thread
2021-03-25 Added dependency on pico-sdk
2021-03-26 Changed rom writer to be an Arduino program sense Pico usb serial doesn't seem to work with C# library
    [Rom.cpp, Rom.hpp, RomWriter.ino]
2021-03-26 Attemptes to fix rom writer still not working
    [Rom.cpp, Rom.hpp, RomWriter.ino]
2021-03-26 Switched to game specific game writing programs; succesfull program running
2021-03-26 Implemented 512kb EEPROM implementation of rom chip to be used with 25LC512; switched to new chip
2021-03-28 Started on assembler: made project, defined ebnf, and updated example.gca to match new assembly
2021-03-28 Set up basic flow of lexer and top level parser
2021-03-29 Added switch for all commands. On to the actual interpretation
2021-03-29 Implemented (untested) mov for spi, bg, spx, and spy
2021-03-30 Added image of v2 PCB
2021-03-30 Added image of cartridge PCB
2021-03-30 Added eagle project to repo
    [card.brd, card.sch, cartridge.brd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]
2021-04-02 Renamed current rom chip to correct name
    [Rom.cpp, Rom.hpp]
2021-07-23 Nuked pico version and switched to cartridge-with-arduino version. Also moved disp code into header (still set up for PICO I2C lib though)
    [card.brd, card.sch, cartridge.brd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]
2021-07-23 Updated description for arduino
2021-07-26 Switched to SoftwareWire library because I could actually get it working and it's built in.
2021-08-03 Added test program for cart board that will show it's been programmed correctly
    [ATtiny84Blink.ino]
2021-08-04 Fixed double folder glitch
    [Ping.ino, Snek.ino]
2021-08-17 Switched to TinyWireM since it's significantly smaller than SoftwareWire
2021-08-17 Fixed Ping after switching to new faster library
    [Ping.ino]
2021-08-17 Modified repo to utilize self-contained cli tools to upload to game card (and to manage libraries) instead of having to manually copy paste libraries and open up Arduino IDE. It also allows for easie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
2021-08-17 Added target which allows me to run the test inos since arduino-cli had made them unrunnable
2021-08-19 Added research into building my own driver into the game card
2021-08-19 Added another i2c circuit

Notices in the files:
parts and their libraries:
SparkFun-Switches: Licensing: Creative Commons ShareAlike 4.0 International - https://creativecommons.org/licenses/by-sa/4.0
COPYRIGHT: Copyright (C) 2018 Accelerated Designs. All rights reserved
